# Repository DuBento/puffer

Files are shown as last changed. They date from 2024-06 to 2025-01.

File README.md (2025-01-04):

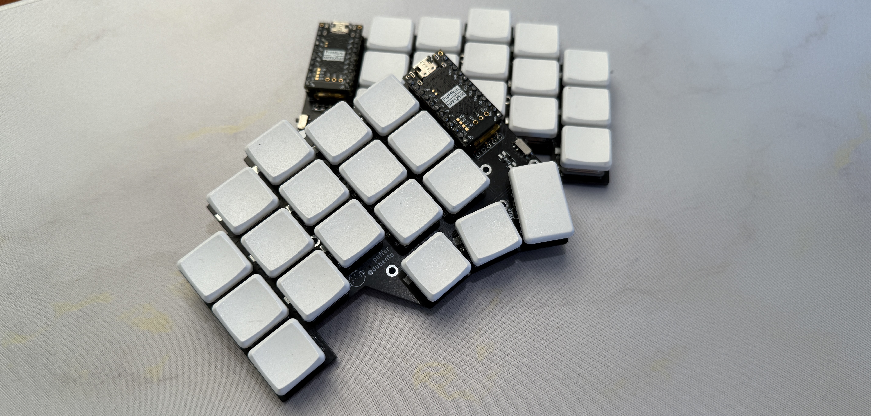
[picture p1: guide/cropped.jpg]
Puffer keyboard


# Puffer

Wireless Ergo Split Mechanical Keyboard.
Based on the [temper keyboard](https://github.com/raeedcho/temper), the Puffer has been upgraded for more comfortable use by those with larger hands.

Only supports Kailh Choc for now.

## Updates

- Increase spacing between keys, from choc spacing (18x17mm) to 19x18mm
- Optional direct soldering of switches or hotswap pads
- Added tenting puck support
- Support for SMD Diodes only

## Features

- 36-key split keyboard 3 rows x 5 columns + 3 thumb keys per half
- Wireless
- Reversible PCB
- Custom spacing 19x18mm
- Nice!Nano (and similar) compatible

## ZMK

[ZMK firmware and personal keymap.](https://github.com/DuBento/zmk-config-puffer)

## Notes

Due to change in overall dimensions this board is not compatible with temper/chocofi cases.

For trying out the dimensions print this [file](print.pdf). 

## Build Guide

Take a look at [Guide](./guide/BUILD.md).

## TODO

- Make case and bottom plate

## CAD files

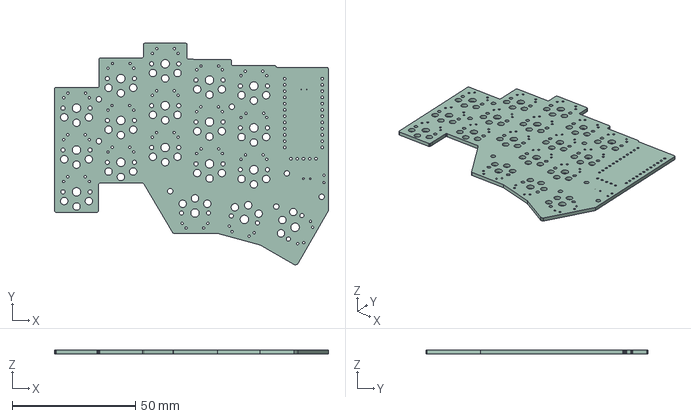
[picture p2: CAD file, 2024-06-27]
pcb/puffer.step
111.3 x 90.0 x 1.60 mm

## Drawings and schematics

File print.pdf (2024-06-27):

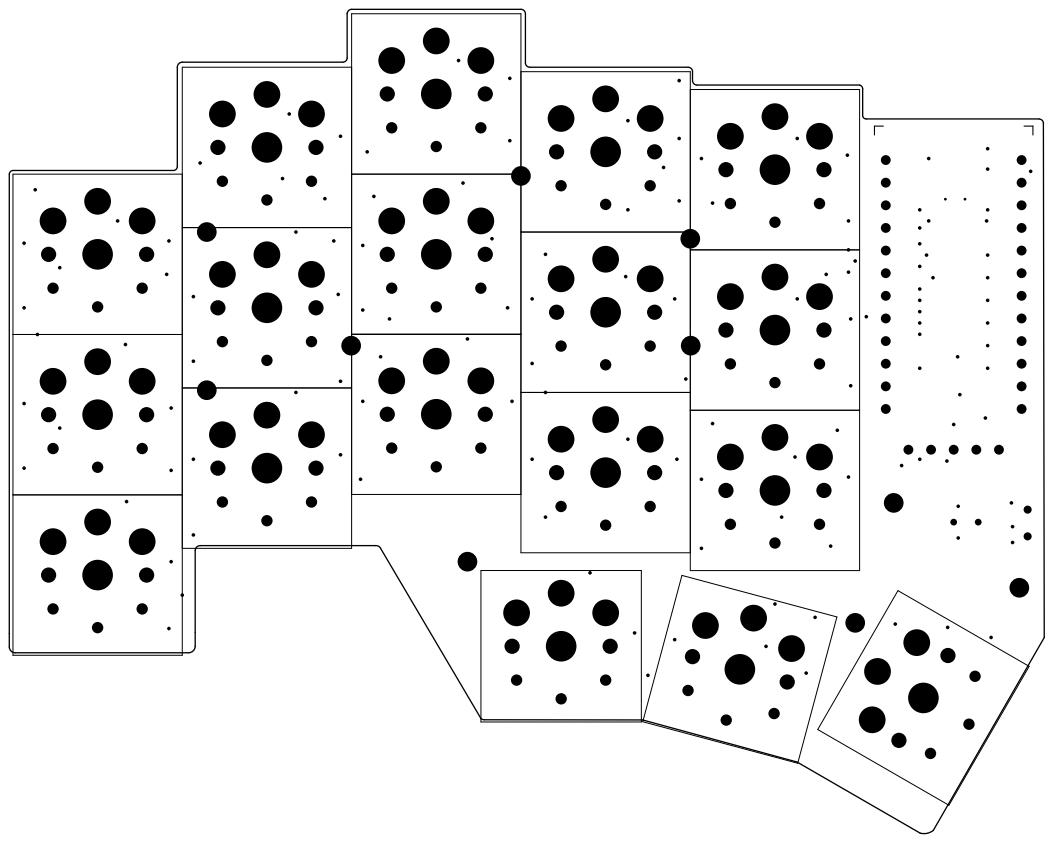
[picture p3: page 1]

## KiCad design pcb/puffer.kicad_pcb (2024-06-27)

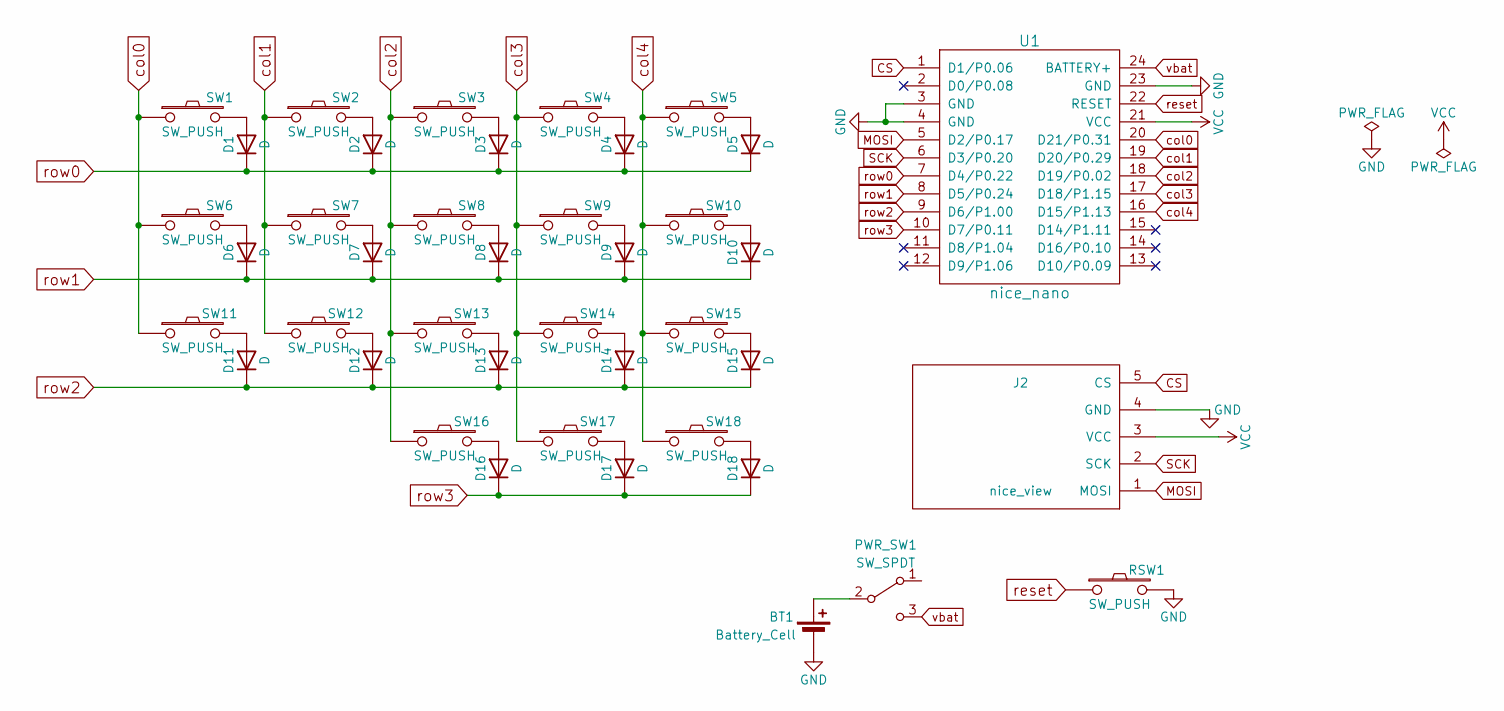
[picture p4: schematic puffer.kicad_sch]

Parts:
BT1: Battery_Cell; Battery_pads_reversible
D1, D2, D3, D4, D5, D6, D7, D8, D9, D10, D11, D12, D13, D14, D15, D16, D17, D18: D; D3_SMD
J2: nice_view; nice_view_jumpers
PWR_SW1: SW_SPDT; power_switch_padreverse
RSW1: SW_PUSH; Panasonic_EVQPUL_EVQPUC_reversible
SW1, SW2, SW3, SW4, SW5, SW6, SW7, SW8, SW9, SW10, SW11, SW12, SW13, SW14, SW15: SW_PUSH; Kailh_socket_PG1350_optional_reversible_expanded
SW16, SW17, SW18: SW_PUSH; Kailh_socket_PG1350_optional_reversible
U1: nice_nano; ProMicro_jumpers

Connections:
CS: J2.5 (CS), U1.1 (D1/P0.06)
GND: BT1.2 (-), J2.4 (GND), RSW1.2, U1.3 (GND), U1.4 (GND), U1.23 (GND)
MOSI: J2.1 (MOSI), U1.5 (D2/P0.17)
unnamed: BT1.1 (+), PWR_SW1.2 (B)
unnamed: D1.2 (A), SW1.2
unnamed: D2.2 (A), SW2.2
unnamed: D3.2 (A), SW3.2
unnamed: D4.2 (A), SW4.2
unnamed: D5.2 (A), SW5.2
unnamed: D6.2 (A), SW6.2
unnamed: D7.2 (A), SW7.2
unnamed: D8.2 (A), SW8.2
unnamed: D9.2 (A), SW9.2
unnamed: D10.2 (A), SW10.2
unnamed: D11.2 (A), SW11.2
unnamed: D12.2 (A), SW12.2
unnamed: D13.2 (A), SW13.2
unnamed: D14.2 (A), SW14.2
unnamed: D15.2 (A), SW15.2
unnamed: D16.2 (A), SW16.2
unnamed: D17.2 (A), SW17.2
unnamed: D18.2 (A), SW18.2
SCK: J2.2 (SCK), U1.6 (D3/P0.20)
VCC: J2.3 (VCC), U1.21 (VCC)
col0: SW1.1, SW6.1, SW11.1, U1.20 (D21/P0.31)
col1: SW2.1, SW7.1, SW12.1, U1.19 (D20/P0.29)
col2: SW3.1, SW8.1, SW13.1, SW16.1, U1.18 (D19/P0.02)
col3: SW4.1, SW9.1, SW14.1, SW17.1, U1.17 (D18/P1.15)
col4: SW5.1, SW10.1, SW15.1, SW18.1, U1.16 (D15/P1.13)
reset: RSW1.1, U1.22 (RESET)
row0: D1.1 (K), D2.1 (K), D3.1 (K), D4.1 (K), D5.1 (K), U1.7 (D4/P0.22)
row1: D6.1 (K), D7.1 (K), D8.1 (K), D9.1 (K), D10.1 (K), U1.8 (D5/P0.24)
row2: D11.1 (K), D12.1 (K), D13.1 (K), D14.1 (K), D15.1 (K), U1.9 (D6/P1.00)
row3: D16.1 (K), D17.1 (K), D18.1 (K), U1.10 (D7/P0.11)
vbat: PWR_SW1.3 (C), U1.24 (BATTERY+)

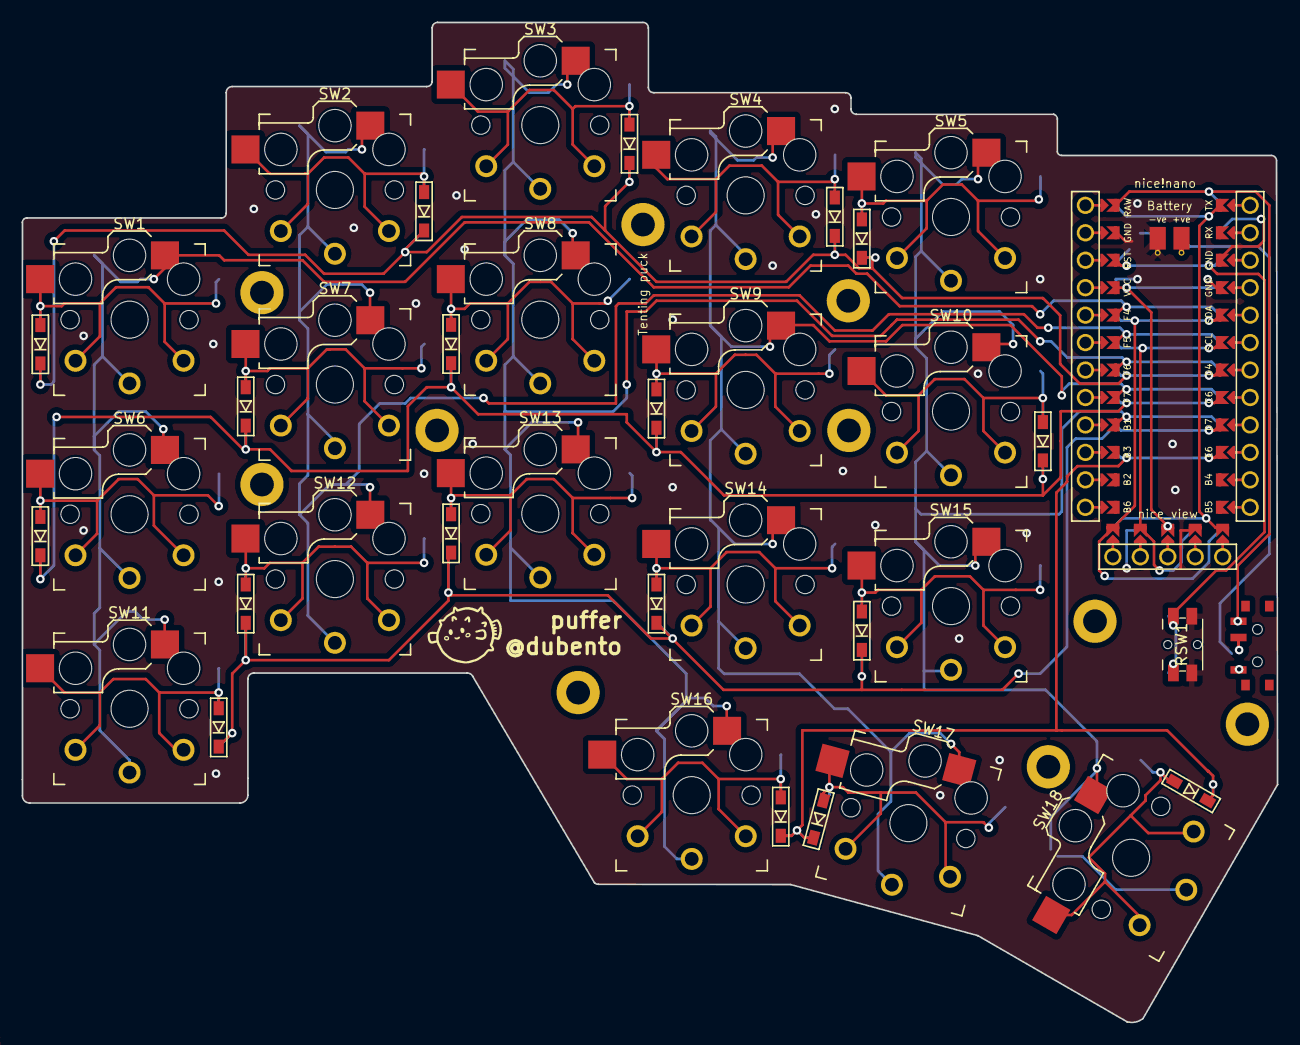
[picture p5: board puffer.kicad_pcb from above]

Board: 2 copper layers, 116.1 x 92.5 mm, 49 parts (0 on the bottom side), 35 nets.

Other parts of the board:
H1: h1; LEGO_HOLE
PUCK1: SYM_Arrow45_Small; Tenting_puck
h2: h2; LEGO_HOLE
h3: h3; LEGO_HOLE
h4: h4; LEGO_HOLE
h5: h5; LEGO_HOLE
h6: h6; LEGO_HOLE
h7: h7; LEGO_HOLE

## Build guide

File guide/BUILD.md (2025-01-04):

## Materials

- 2x PCB (gerber files in [releases](https://github.com/DuBento/puffer/releases))
- 2x nice!nanos (or [alternatives](https://github.com/joric/nrfmicro/wiki/Alternatives))
- 2x LiPo batteries 301230 to fit under the microcontroller 
- 2x SPDT SMD toggle switches (for ON/OFF)
- 36x Kailh choc v1 switches
- (Optional) 36x Kailh choc hotswap sockets
- 36x Choc v1 keycaps
- 36x 1N4148 SOD-123 SMD diodes
- Female MCU socket

## Photo log

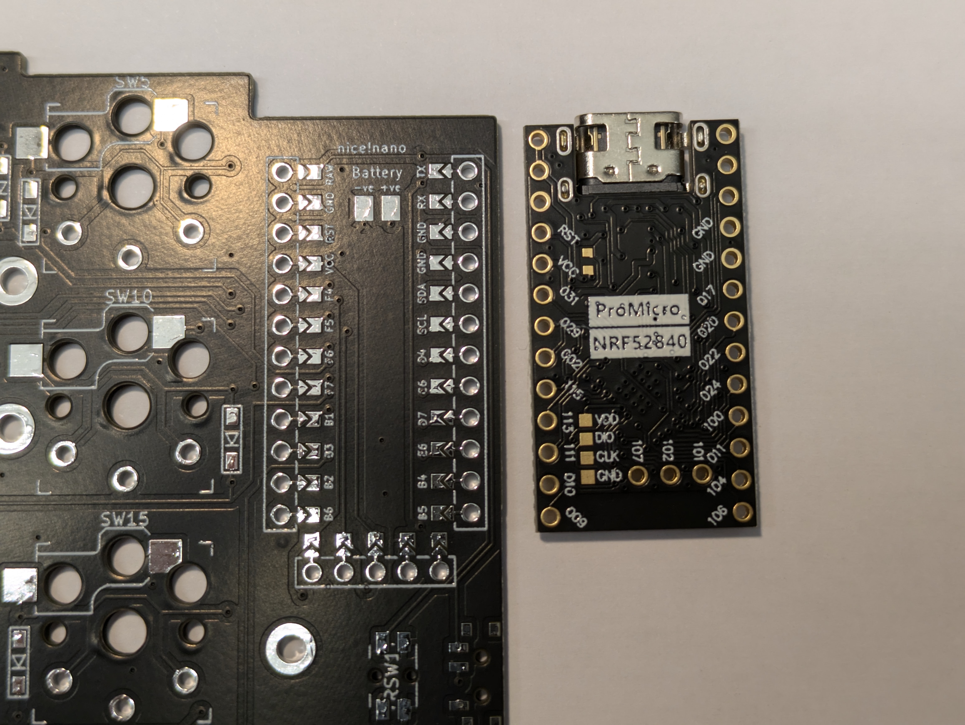
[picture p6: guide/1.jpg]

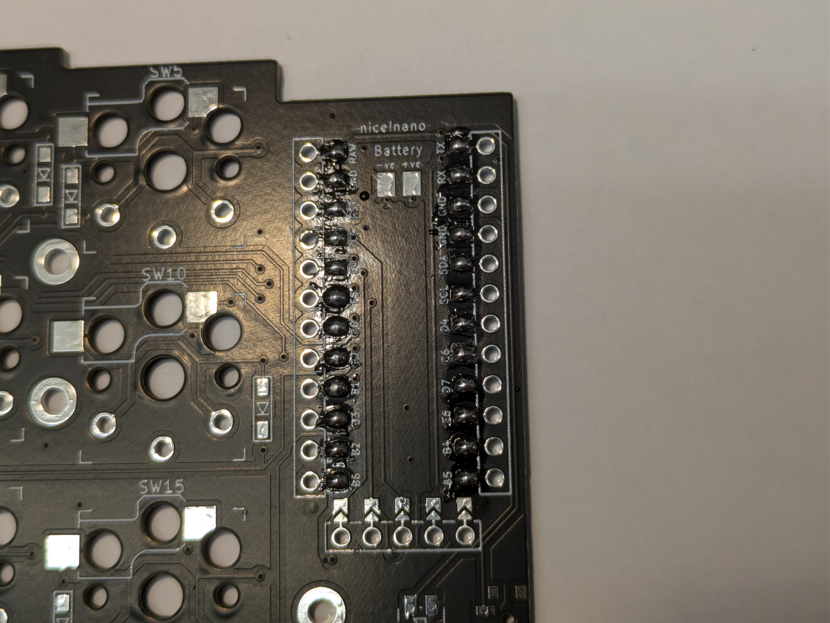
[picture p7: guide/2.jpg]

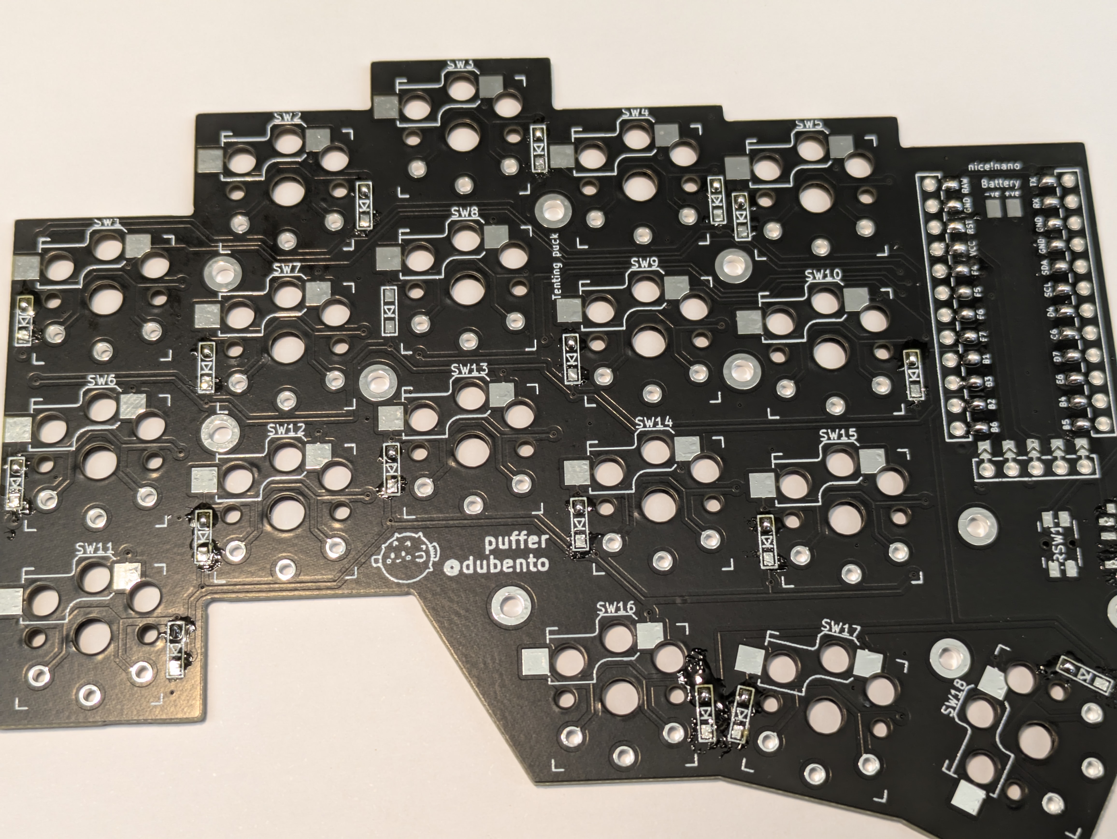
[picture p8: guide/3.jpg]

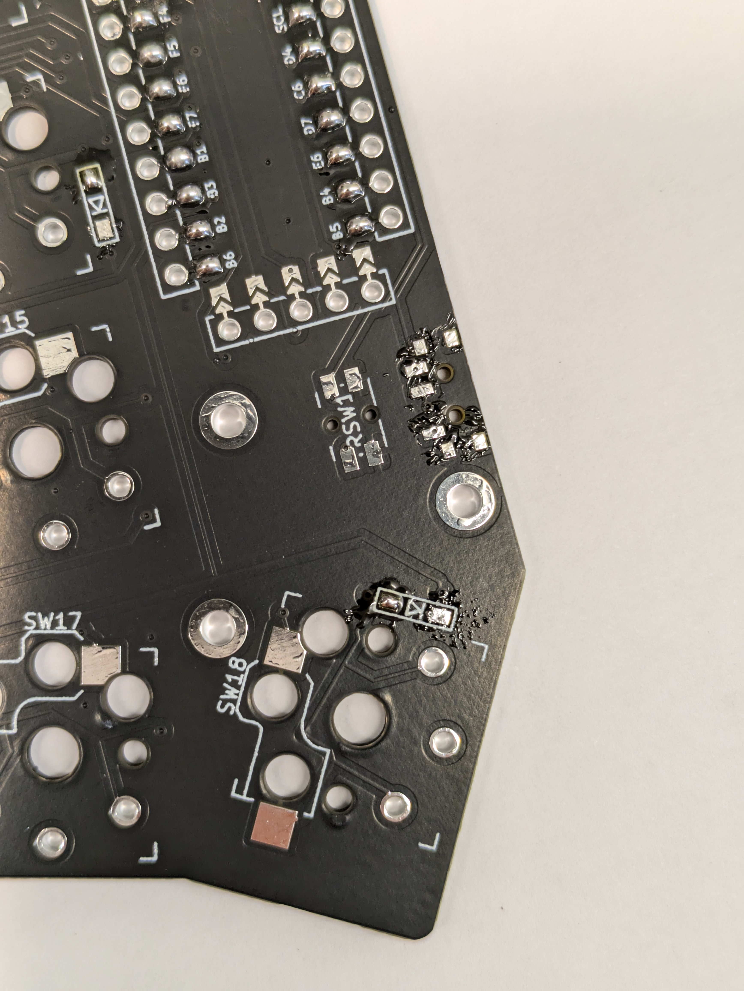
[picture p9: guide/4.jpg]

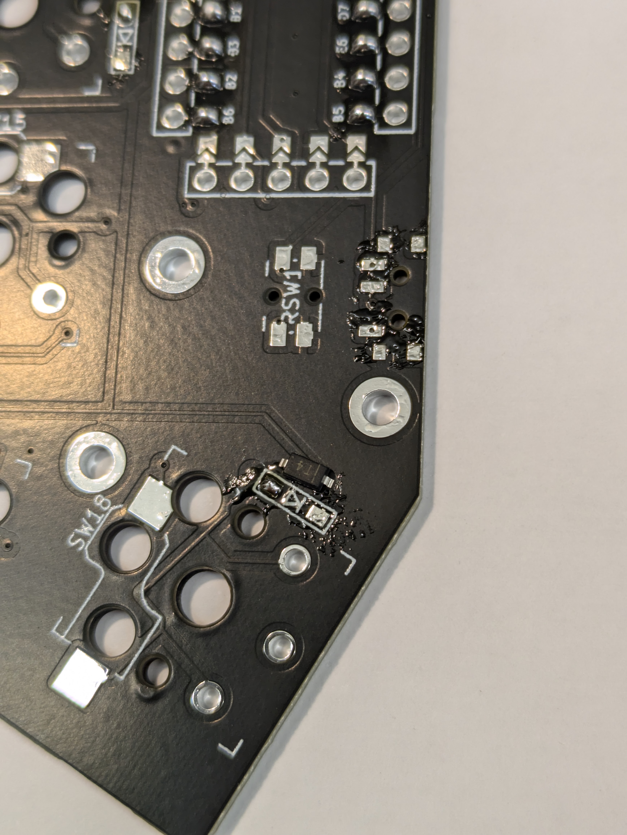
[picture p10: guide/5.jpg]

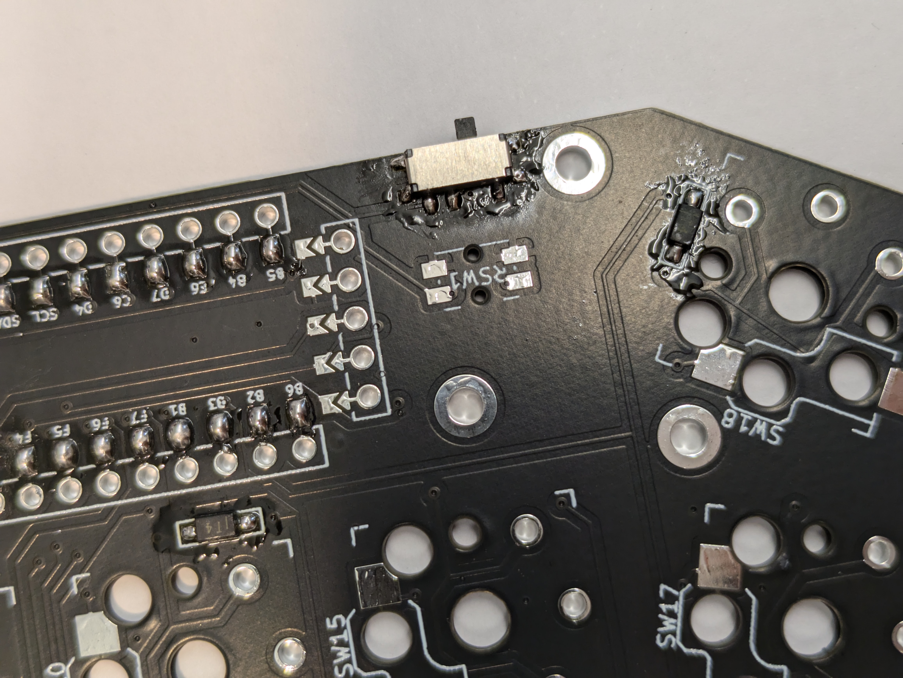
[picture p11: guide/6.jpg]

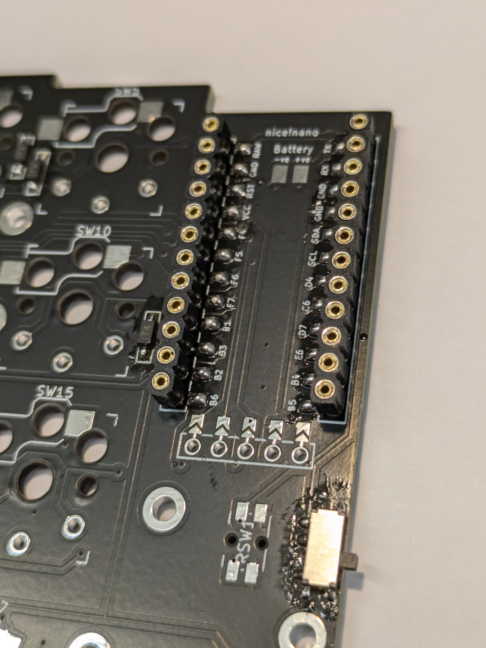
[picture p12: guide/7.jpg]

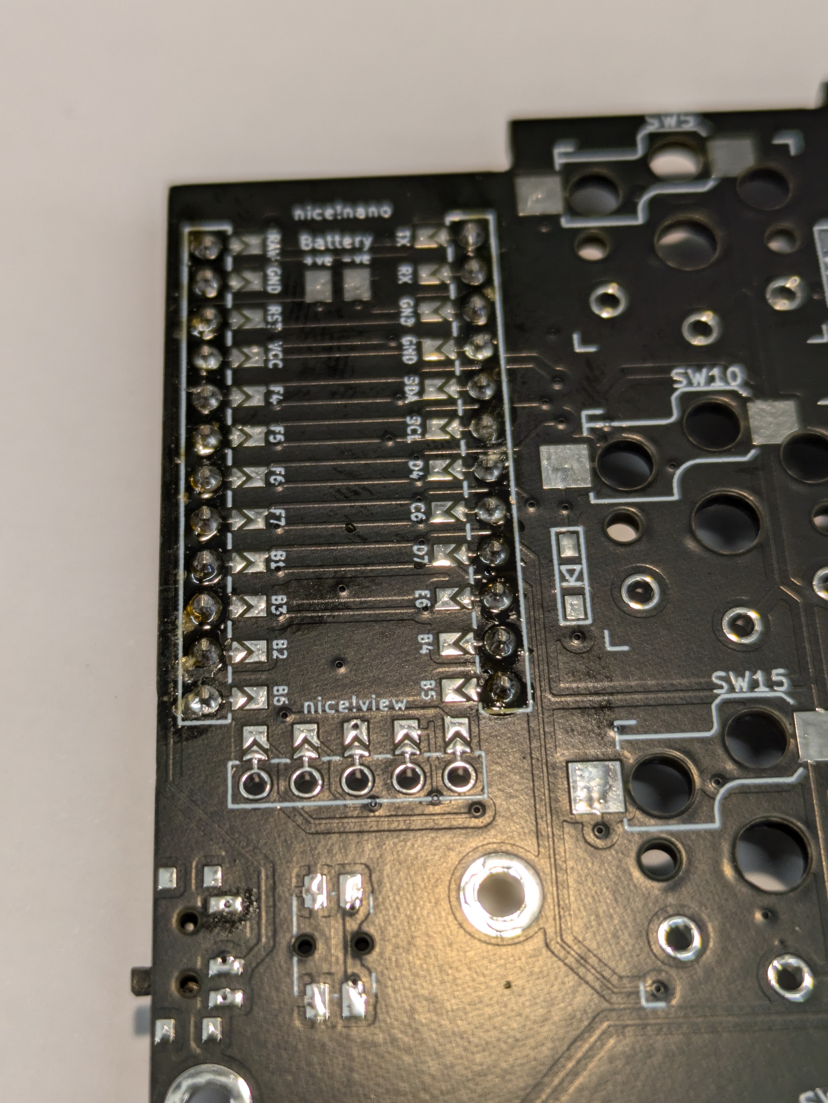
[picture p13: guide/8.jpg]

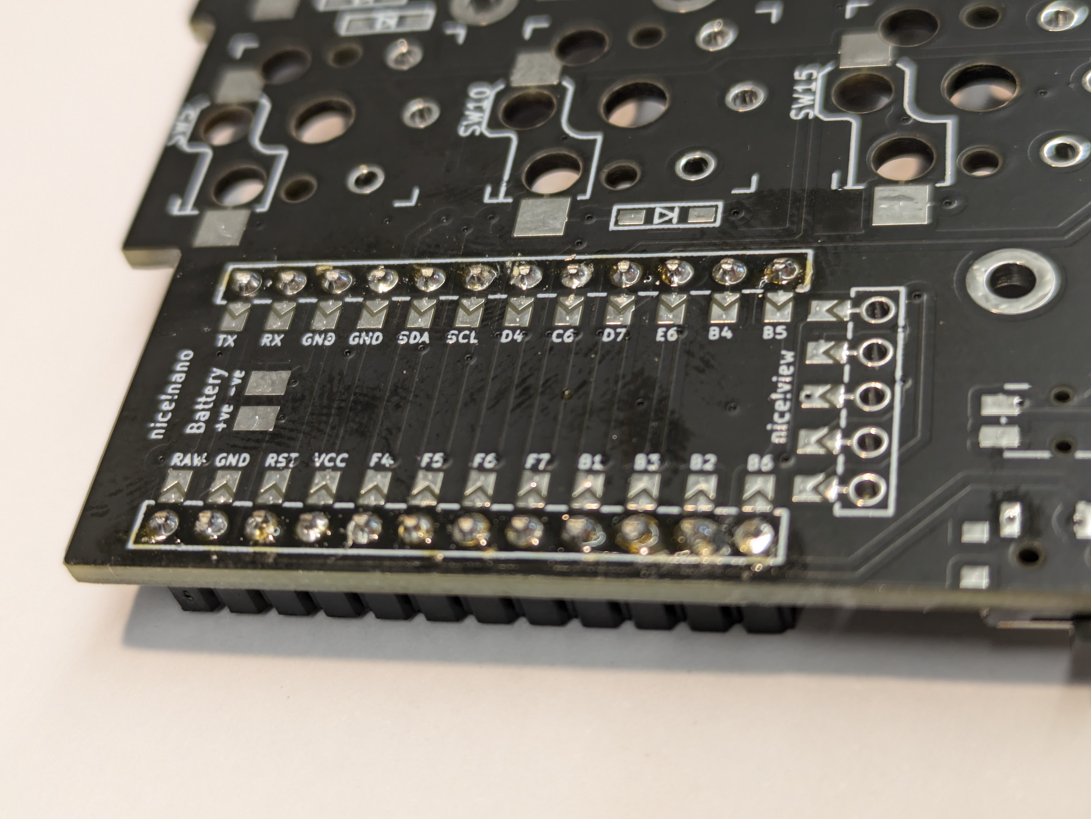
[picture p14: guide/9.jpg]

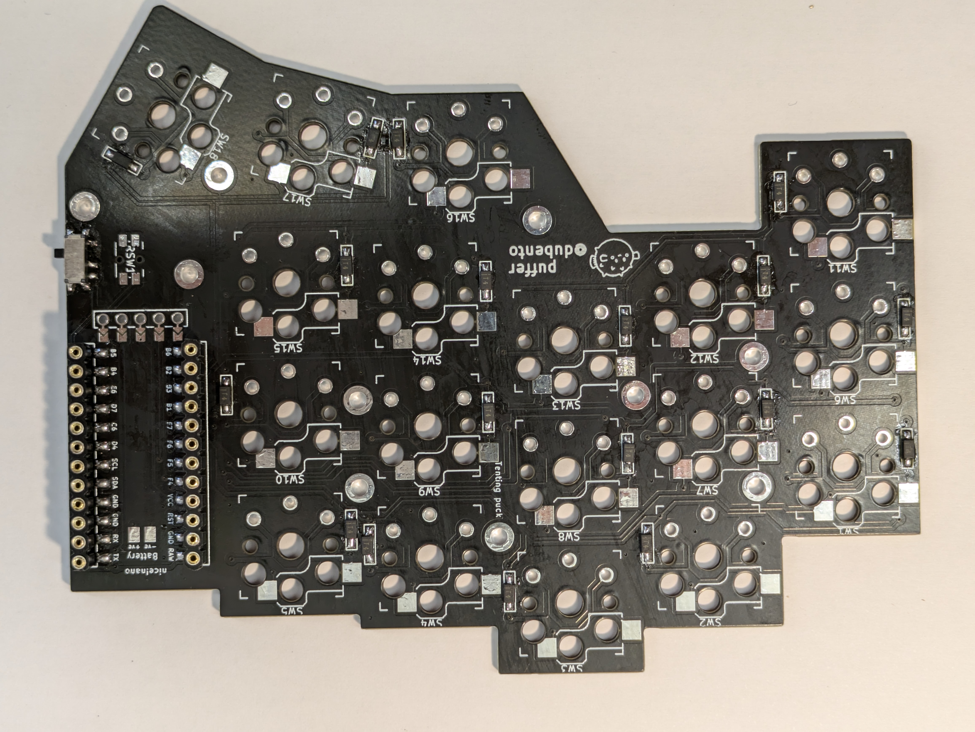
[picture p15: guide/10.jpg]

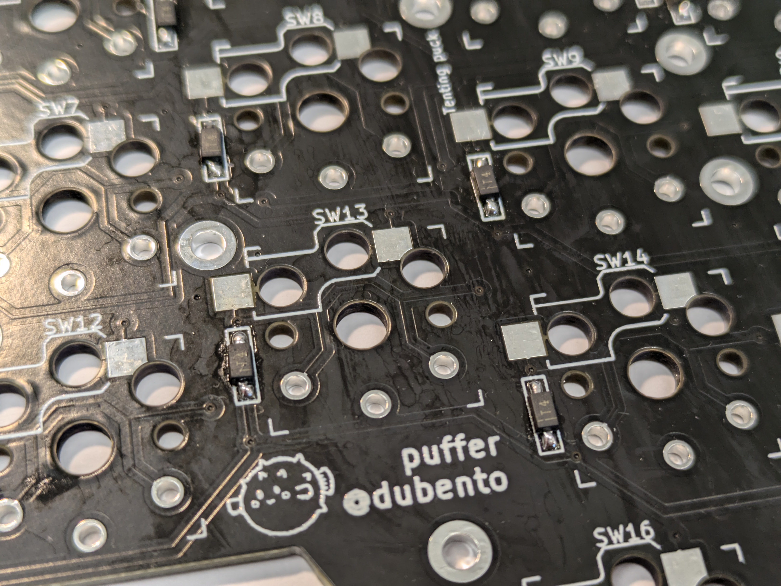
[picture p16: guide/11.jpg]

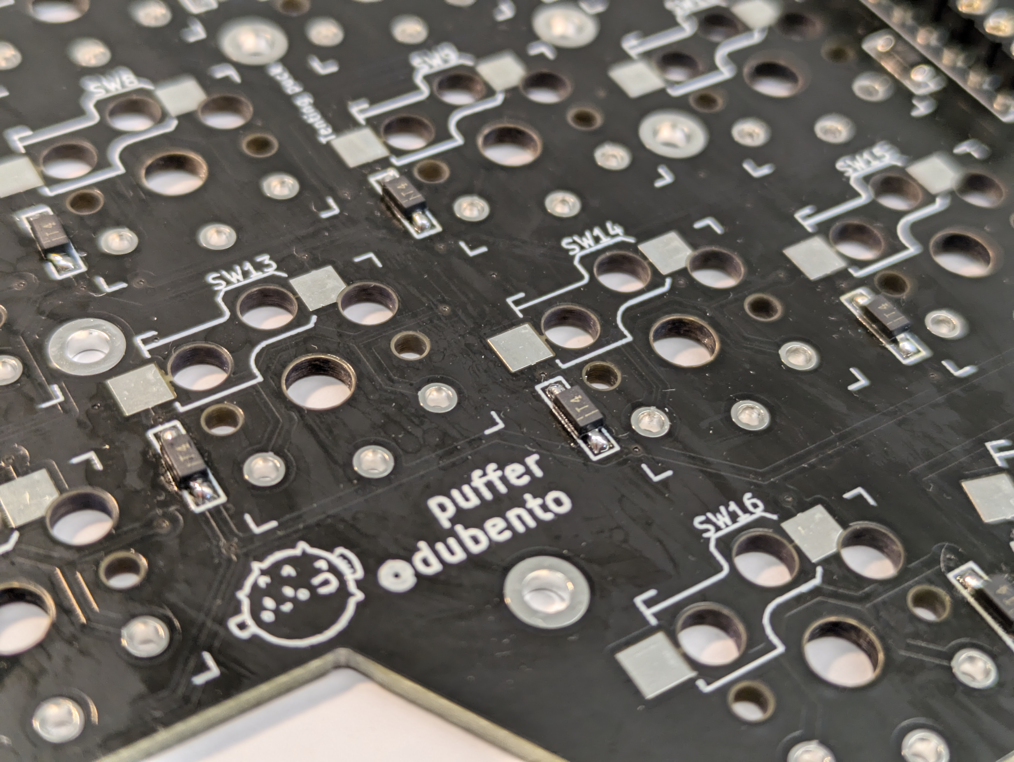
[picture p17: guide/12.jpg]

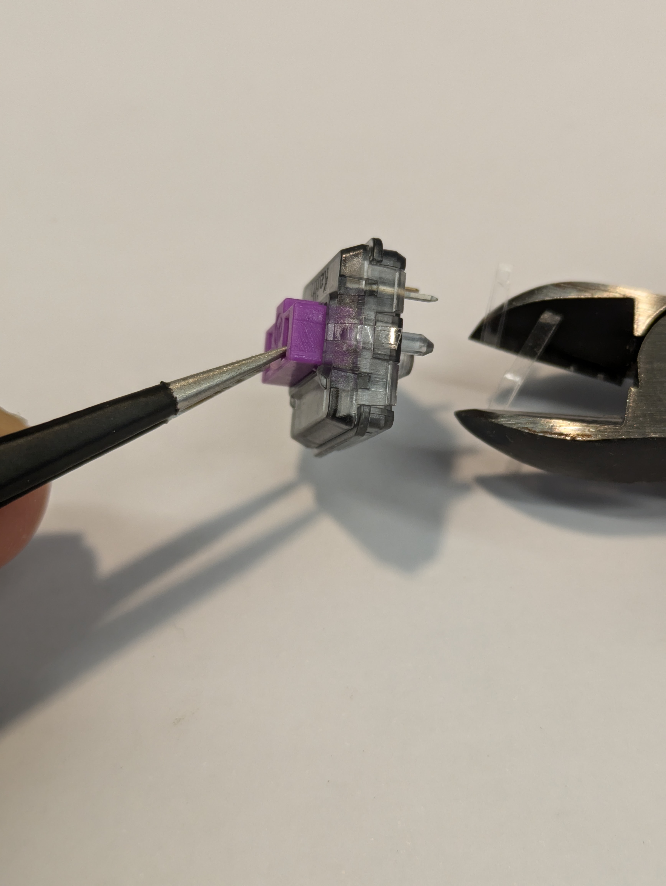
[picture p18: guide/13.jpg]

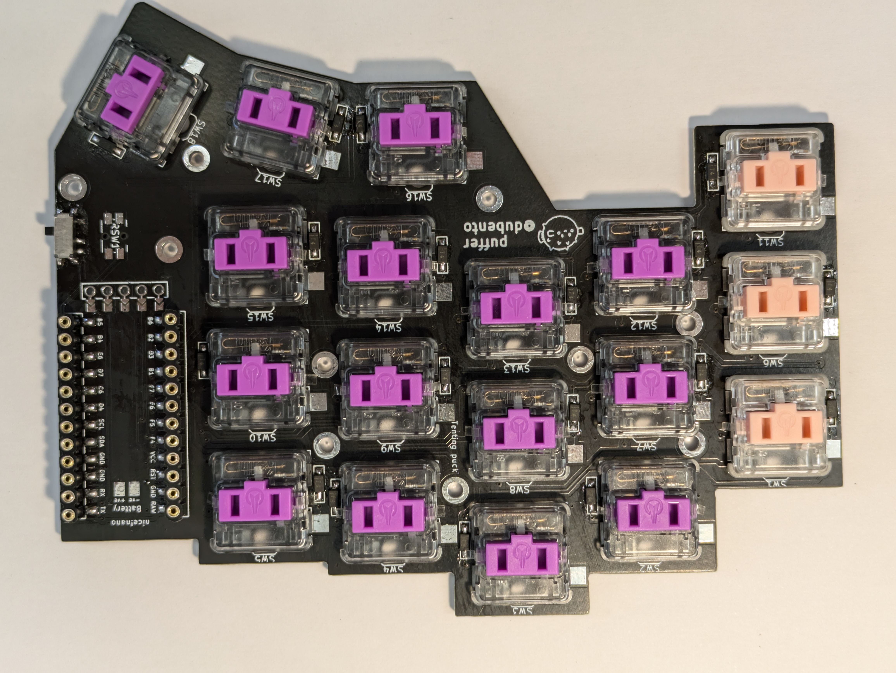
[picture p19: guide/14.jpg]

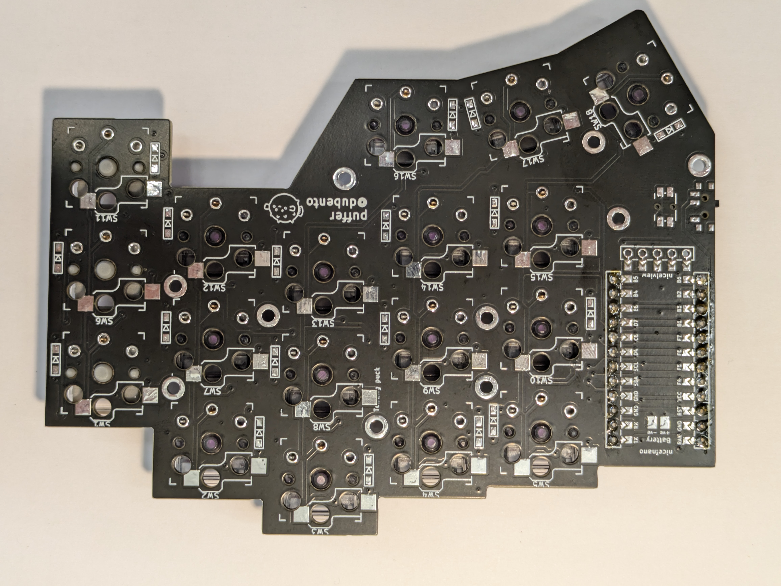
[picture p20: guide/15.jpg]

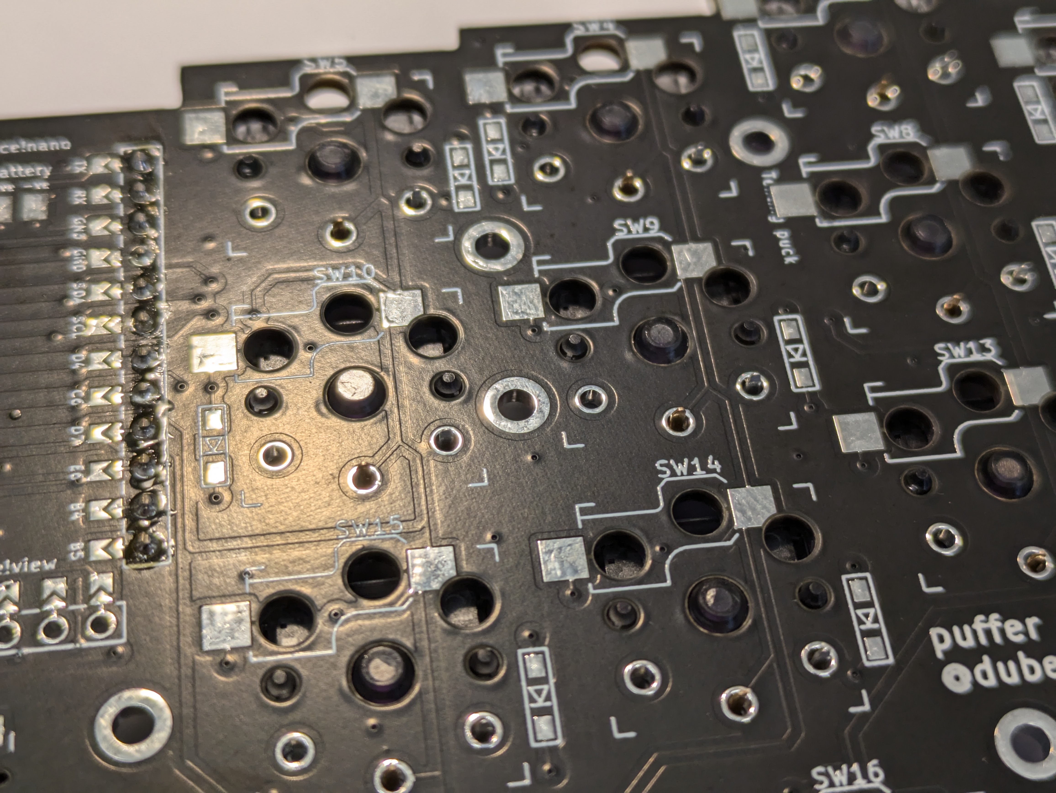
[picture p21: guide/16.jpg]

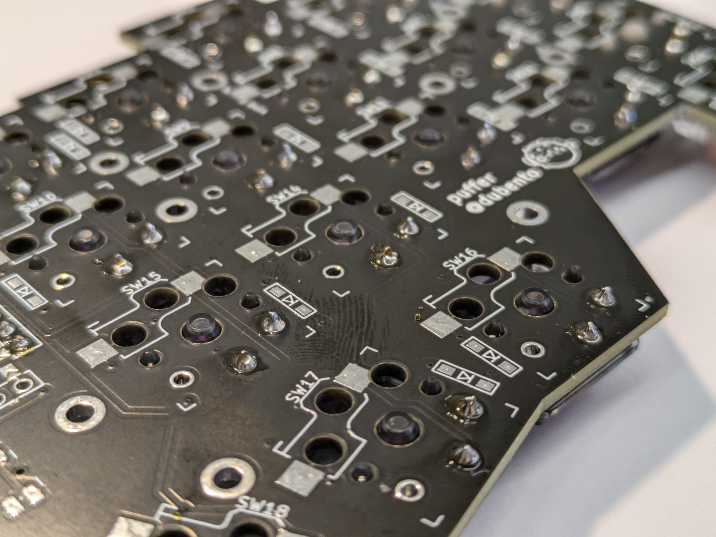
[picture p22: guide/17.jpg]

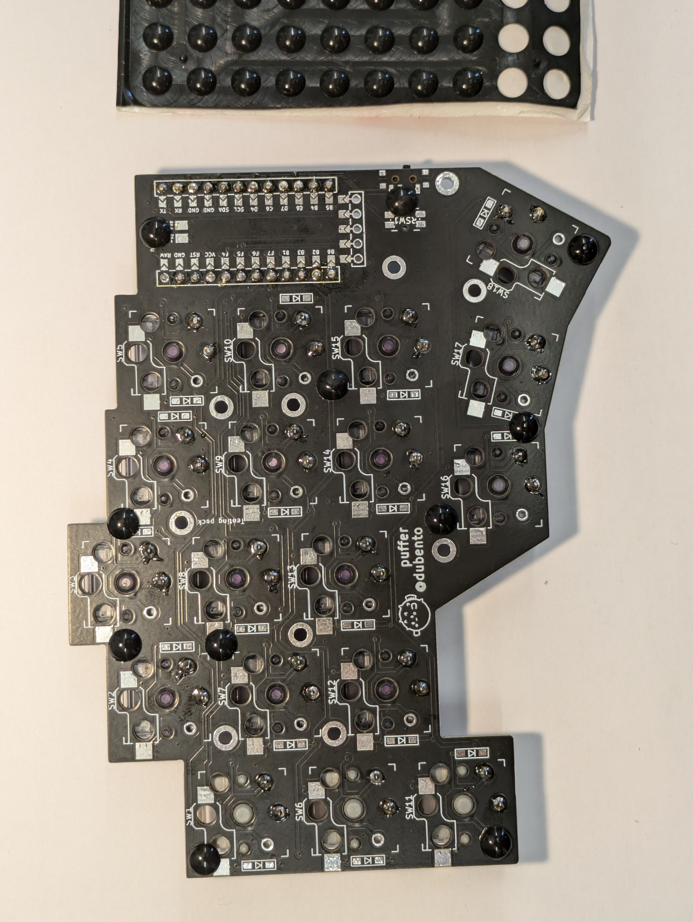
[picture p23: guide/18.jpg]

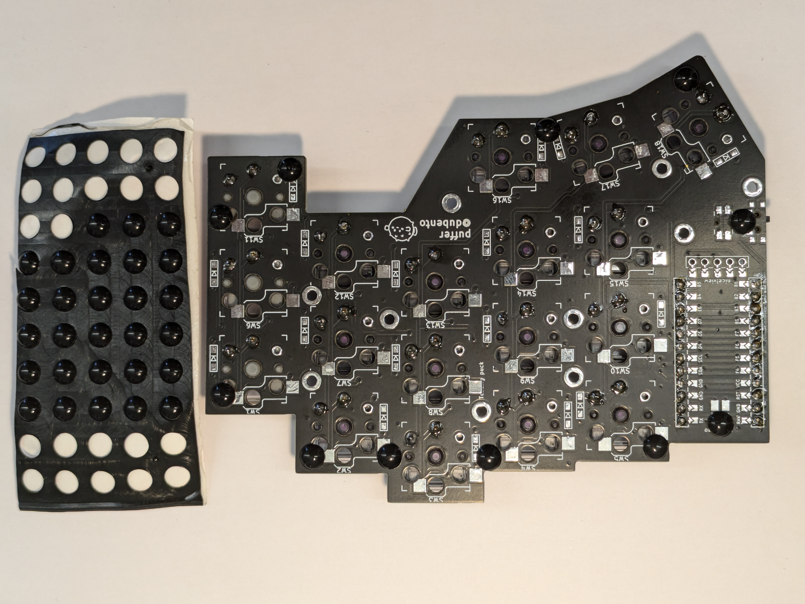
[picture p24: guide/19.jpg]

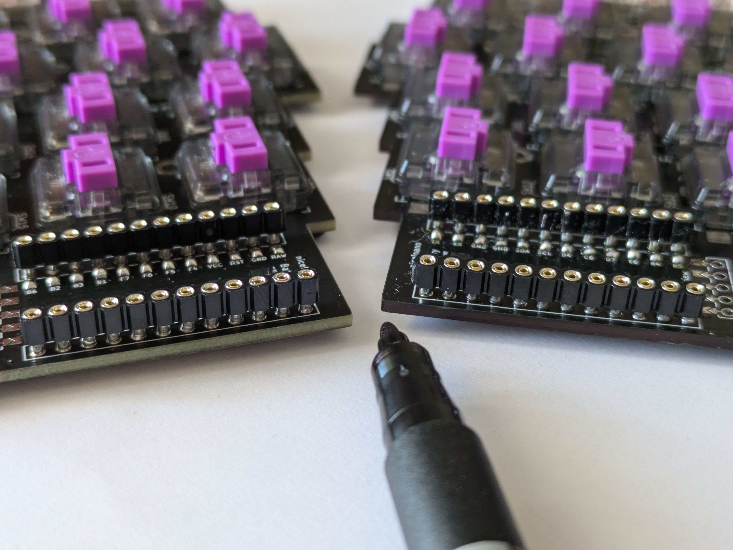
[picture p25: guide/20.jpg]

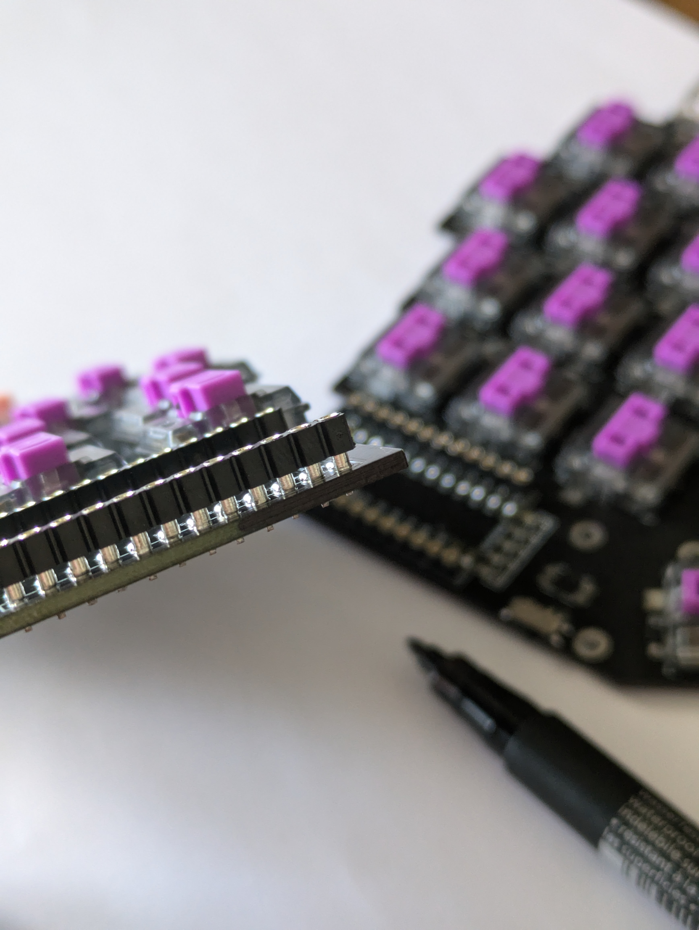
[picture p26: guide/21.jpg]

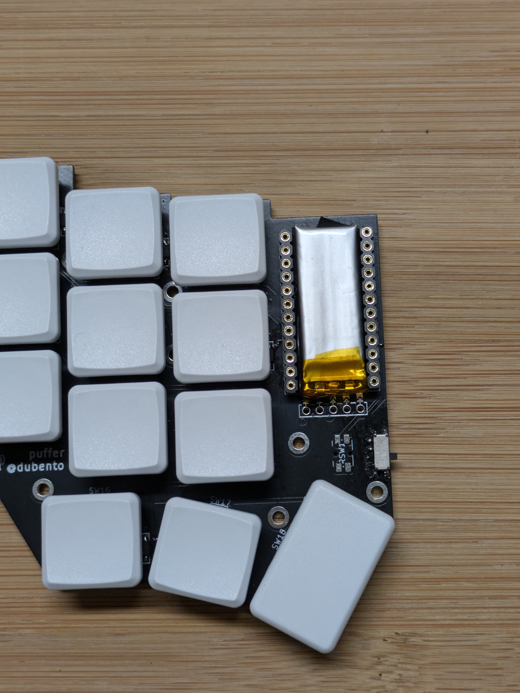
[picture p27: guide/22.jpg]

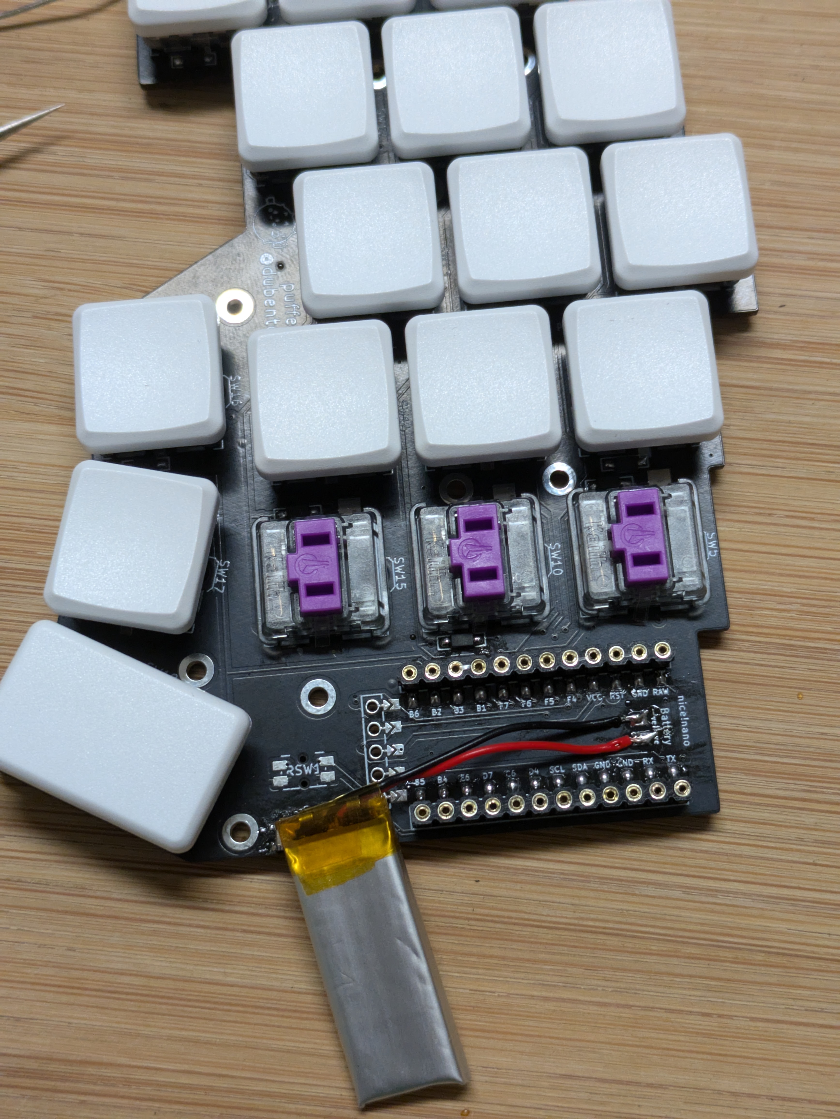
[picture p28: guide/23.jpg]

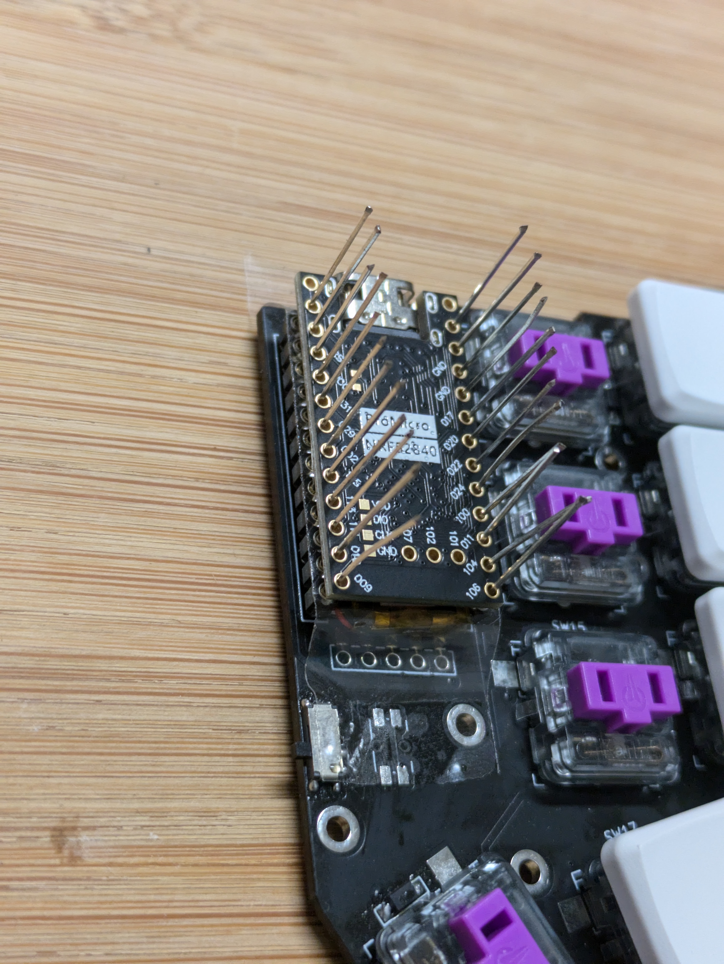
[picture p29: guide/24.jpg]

finished
